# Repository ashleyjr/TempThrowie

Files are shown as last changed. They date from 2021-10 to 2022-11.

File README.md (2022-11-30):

# TempThrowie: Install

## MCUs

   - SDCC : mcs51/z80/z180/r2k/r3ka/gbz80/tlcs90/ds390/TININative/ds400/hc08/s08/stm8 3.5.0
   - SimplicityStudio_v5 flash8051

      - Download from Silicon Labs website
      - Requires 8-bit additonal tools which can be downloaded inside the studio 

   - Silicon Labs 8-Bit USB Debug Adapter

## Basestation (Raspberry Pi)

   - Basestation is a Raspberry Pi Model B Plus Rev 1.2
   - Fresh install of Raspbian GNU/Linux 11 (bullseye)
   - pip install matplotlib
   - sudo apt-get install libatlas-base-dev
   - pip install numpy --upgrade
   - sudo apt install apache2 -y
   - sudo apt-get install php libapache2-mod-php 
   - Config:

```
(21:10 pi@raspberrypi ~) > crontab -l | tail -n 1
*/20 * * * * cd /home/pi/TempThrowie/receiver/software/base/; python throwieAnalysis.py --stats --log stats.log; python throwieAnalysis.py --plotbatttoday --out ../webpage/batttoday.png --log batttoday.log; python throwieAnalysis.py --plottemptoday --out ../webpage/temptoday.png --log temptoday.log; python throwieAnalysis.py --plotbattweek --out ../webpage/battweek.png --log battweek.log; python throwieAnalysis.py --plottempweek --out ../webpage/tempweek.png --log tempweek.log
(21:10 pi@raspberrypi ~) > tail -n 5 /etc/rc.local 
# Run TempThrowie UART monitor
rm /home/pi/TempThrowie/receiver/software/base/throwie.db
cd /home/pi/TempThrowie/receiver/software/base; python throwieLogging.py &

exit 0
(21:10 pi@raspberrypi ~) > cat /etc/apache2/sites-available/000-default.conf | grep DocumentRoot
	DocumentRoot /home/pi/TempThrowie/receiver/software/webpage/
(21:10 pi@raspberrypi ~) > cat /etc/apache2/apache2.conf | grep TempThrowie -A4
<Directory /home/pi/TempThrowie/receiver/software/webpage/>
	Options Indexes FollowSymLinks
	AllowOverride None
	Require all granted
</Directory>
(21:10 pi@raspberrypi ~) > 
```

## Basestation (Laptop)

   - MacBook Pro 2019
   - Virtual Box Virtual Machine
   - Ubuntu 20.04.4 LTS
   - sudo update-alternatives --install /usr/bin/python python /usr/bin/python3 10
   - sudo apt-get install python3-pip
   - python -m pip install pyserial 
   - python -m pip install matplotlib
   - sudo apt install imagemagick-6.q16

# TempThrowie: Spec

## Throwie

### Transmitter

#### Physical

   - Amplitude Modulated (AM) 
   - On Off Keying (OOK) 
   - 433MHz carrier
   - Asynchronous 1K bits per second (pbs) bit stream 

#### Packet

   - A packet is formed of 64 bytes
   - Each byte is sent least signifiant bit first in the following order
     with no spaces

      - Byte0:  The preamble code 0xAA/0x10101010
         ...
      - Byte58: The preamble code 0xAA/0x10101010
      - Byte59: The start code 0x6A/0b01101010
      - Byte60: The throwie identity (ID)
      - Byte61: The temperature reading
      - Byte62: The battery reading
      - Byte63: XOR (Byte3 ^ (Byte2 ^ Byte1))  

#### Collisions

   - Within a collection of throwies the transmit intervals are asynchronous
   
   - A packet is transmitted every 10 minutes
   
   - The 40 bits in each packet takes 40ms to transmit

   - Probability of a collision

      - x = ((n-1) * d) / t

      - n = Number of thowies in collection

      - d = Duration of tranmissions (seconds) = 0.04

      - t = Transmit interval (seconds) = 600

   - Probability of failure when n is

      - 2:     x = 0,04 / 600          = 6.6 * 10^-5
      - 10:    x = (9 * 0,04) / 600    = 6   * 10^-4
      - 256:   x = (255 * 0,04) / 600  = 1.7 * 10^-2
   
   - Mean time between failure at 144 transmissions a day when n is
      
      - 2:     105 days 
      - 10:    12 days    
      - 256:   0.41 days

   - **This does not include failures caused by interference from other devices**

### Measurements

#### Temperature

   - Range between -10C and 50C
   - In the transmitted byte encoding each increment is worth 0.234C ((50 - (-10))/256) 
   - The offset is not calibrated

#### Battery

   - Range between 3.3V and 7V
   - In the transmitted byte encoding each increment is worth 0.014V ((7 - 3.3)/256) 
   - The offset is calibrated and 0 represent the lower voltage

## Receiver

### The serial port 
   
   - Has a baud rate of 115200
   - Transmits 1 start bit 
   - Transmits 8 bit data frame most significant bit first 
   
### Hardware

   - TODO: Spec RF receiver

   - The microcontroller is continually monitoring the output of the receiver 
   - The sample rate is 2KHz 
   - There is a pattern detector searching for the following 8 bytes

      - Byte0: 0b?1?0?1?0
         ...
      - Bytes6: 0b?1?0?1?0
      - Bytes7: 0b?0?1?1?0

   - When the code is detected the next 8 bytes are placed in to a buffer
     and immediately transmitted over the serial port
   - When the last byte is transmitted the microcontroller goes back to 
     pattern detection

### Computer

   - The receiver hardware is connected to a host computer using a serial port   
   - There are two scripts running on the computer

      - The *Logging Script* is continuously running and writing data 
      - The *Analysis Script* may be envoked at anytime and reads the data
       
#### Logging Script

   - The script is called *throwieLogging.py*
   - The serial port is continuously monitored 
   
      - When a frame is received a timeout window opens 
      - The window closes when no frame is recieved for 2 seconds
      - While the window is open all frames received are placed in to a buffer
      - The depth of the buffer is 500 Bytes

         - As the sample rate of the microcontroller is 2KHz it is impossible to 
           overflow this buffer

   - When the timeout window closes 
      
      - A string is created by draining the buffer
      - Each byte is converted to a two character hexadecimal string   
      - More bytes are added to the right hand side of the string 
      - When the buffer is fully drained the left hand side contains the first byte
        recieved and right hand side contained the last byte recieved

   - The string is written to a log file

      - The file is called **throwie_YYYYMMDD_HHSS.log**

         - Y = Year
         - M = Month
         - D = Day
         - H = Hour (24h)
         - M = Minute

      - The file is located in the same directory as the script  

#### Analysis Script

   - The script is called *throwieAnalysis.py*
   - The setup phase

      - Will open every log file in chronological order
      - Create a list of transmissions containing 

         - The date
         - The time
         - The 

      - If the log file contains 8 bytes of data it will analyse

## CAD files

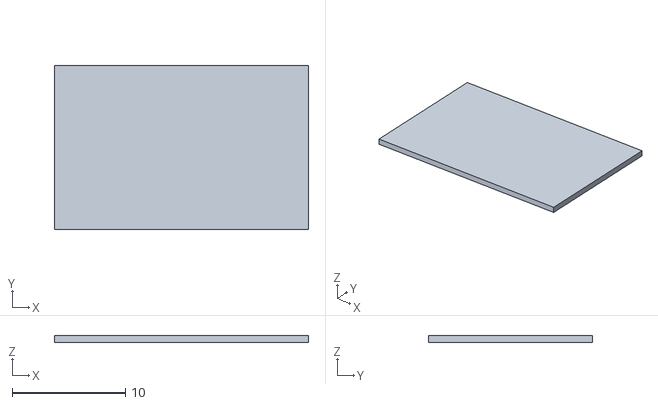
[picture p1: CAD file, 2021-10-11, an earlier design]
throwie/caseworks/RevA/pcb.stl
22.4 x 14.5 x 0.6

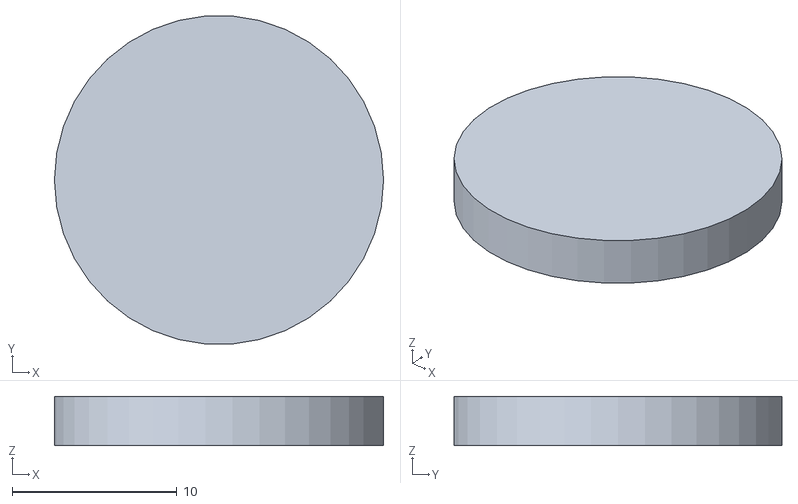
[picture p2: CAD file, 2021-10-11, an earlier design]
throwie/caseworks/RevA/battery.stl
20.0 x 19.9 x 3.00

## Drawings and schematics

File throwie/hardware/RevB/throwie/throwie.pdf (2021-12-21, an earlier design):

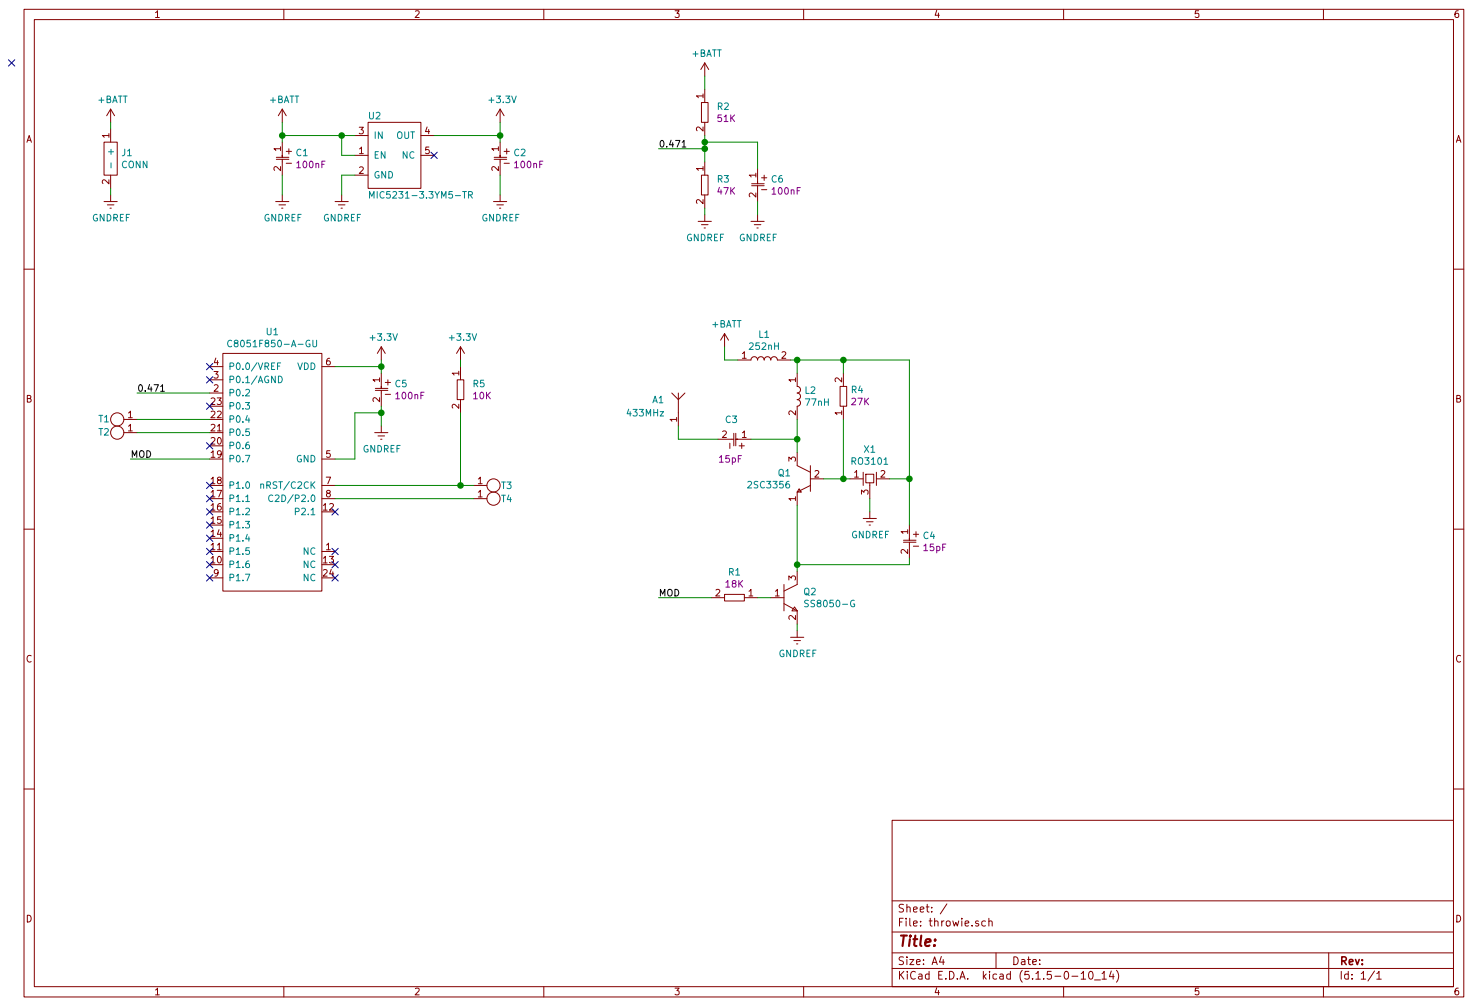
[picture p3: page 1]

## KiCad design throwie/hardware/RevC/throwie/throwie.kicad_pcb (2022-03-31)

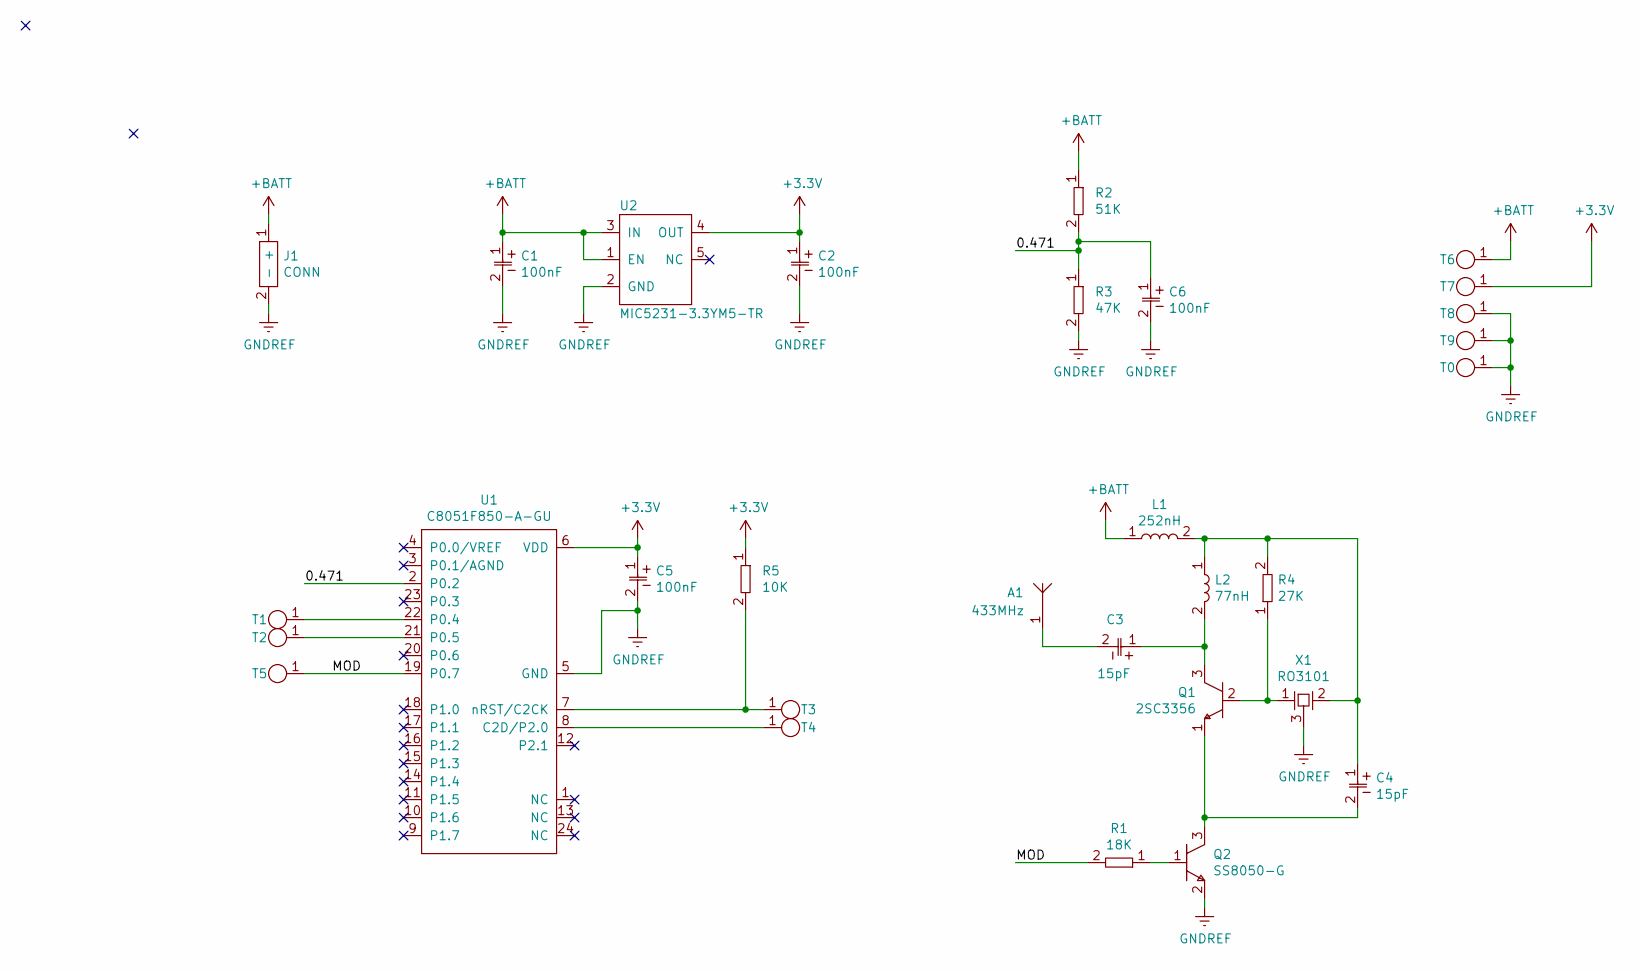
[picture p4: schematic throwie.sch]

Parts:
A1: 433MHz
C1, C2, C3, C4, C5, C6: CAP_0603; 0603
J1: CONN
L1: 252nH
L2: 77nH
Q1: 2SC3356
Q2: SS8050-G
R1, R2, R3, R4, R5: RES_0603; 0603
T0, T1, T2, T3, T4, T5, T6, T7, T8, T9: TestPoints; TestPoint
U1: C8051F850-A-GU
U2: MIC5231-3.3YM5-TR; MIC5231
X1: RO3101; R03101

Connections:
+3V3: C2.1, C5.1, R5.1, T7.1, U1.6 (VDD), U2.4 (OUT)
+BATT: C1.1, J1.1 (+), L1.1, R2.1, T6.1, U2.1 (EN), U2.3 (IN)
/0.471: C6.1, R2.2, R3.1, U1.2 (P0.2)
/MOD: R1.2, T5.1, U1.19 (P0.7)
GNDREF: C1.2, C2.2, C5.2, C6.2, J1.2 (-), Q2.2, R3.2, T0.1, T8.1, T9.1, U1.5 (GND), U2.2 (GND), X1.3
unnamed: A1.1, C3.2
unnamed: C3.1, L2.2, Q1.3
unnamed: C4.1, L1.2, L2.1, R4.2, X1.2
unnamed: C4.2, Q1.1, Q2.3
unnamed: Q1.2, R4.1, X1.1
unnamed: Q2.1, R1.1
unnamed: R5.2, T3.1, U1.7 (nRST/C2CK)
unnamed: T1.1, U1.22 (P0.4)
unnamed: T2.1, U1.21 (P0.5)
unnamed: T4.1, U1.8 (C2D/P2.0)

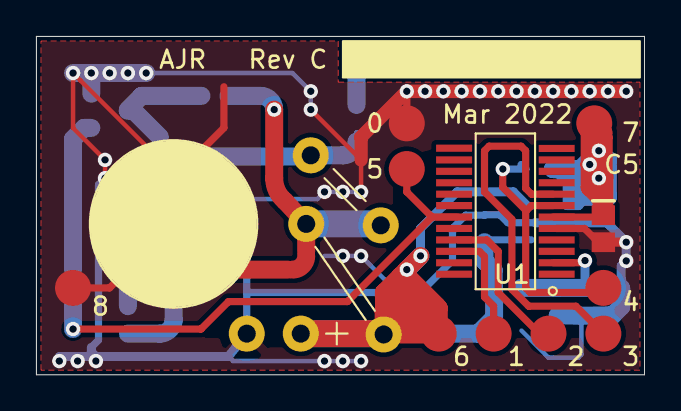
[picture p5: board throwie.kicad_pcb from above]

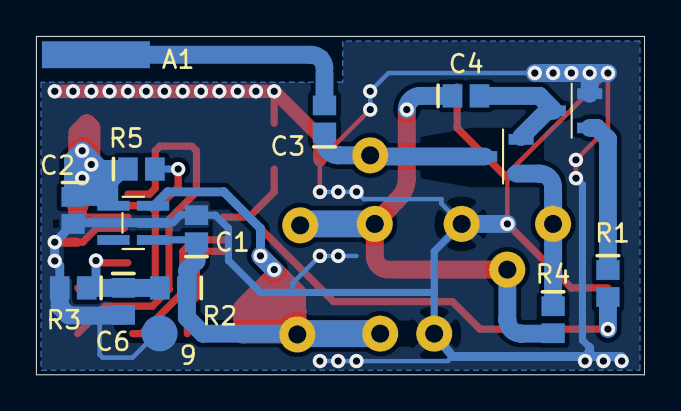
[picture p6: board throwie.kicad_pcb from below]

Board: 2 copper layers, 33.8 x 18.8 mm, 30 parts (15 on the bottom side), 15 nets.

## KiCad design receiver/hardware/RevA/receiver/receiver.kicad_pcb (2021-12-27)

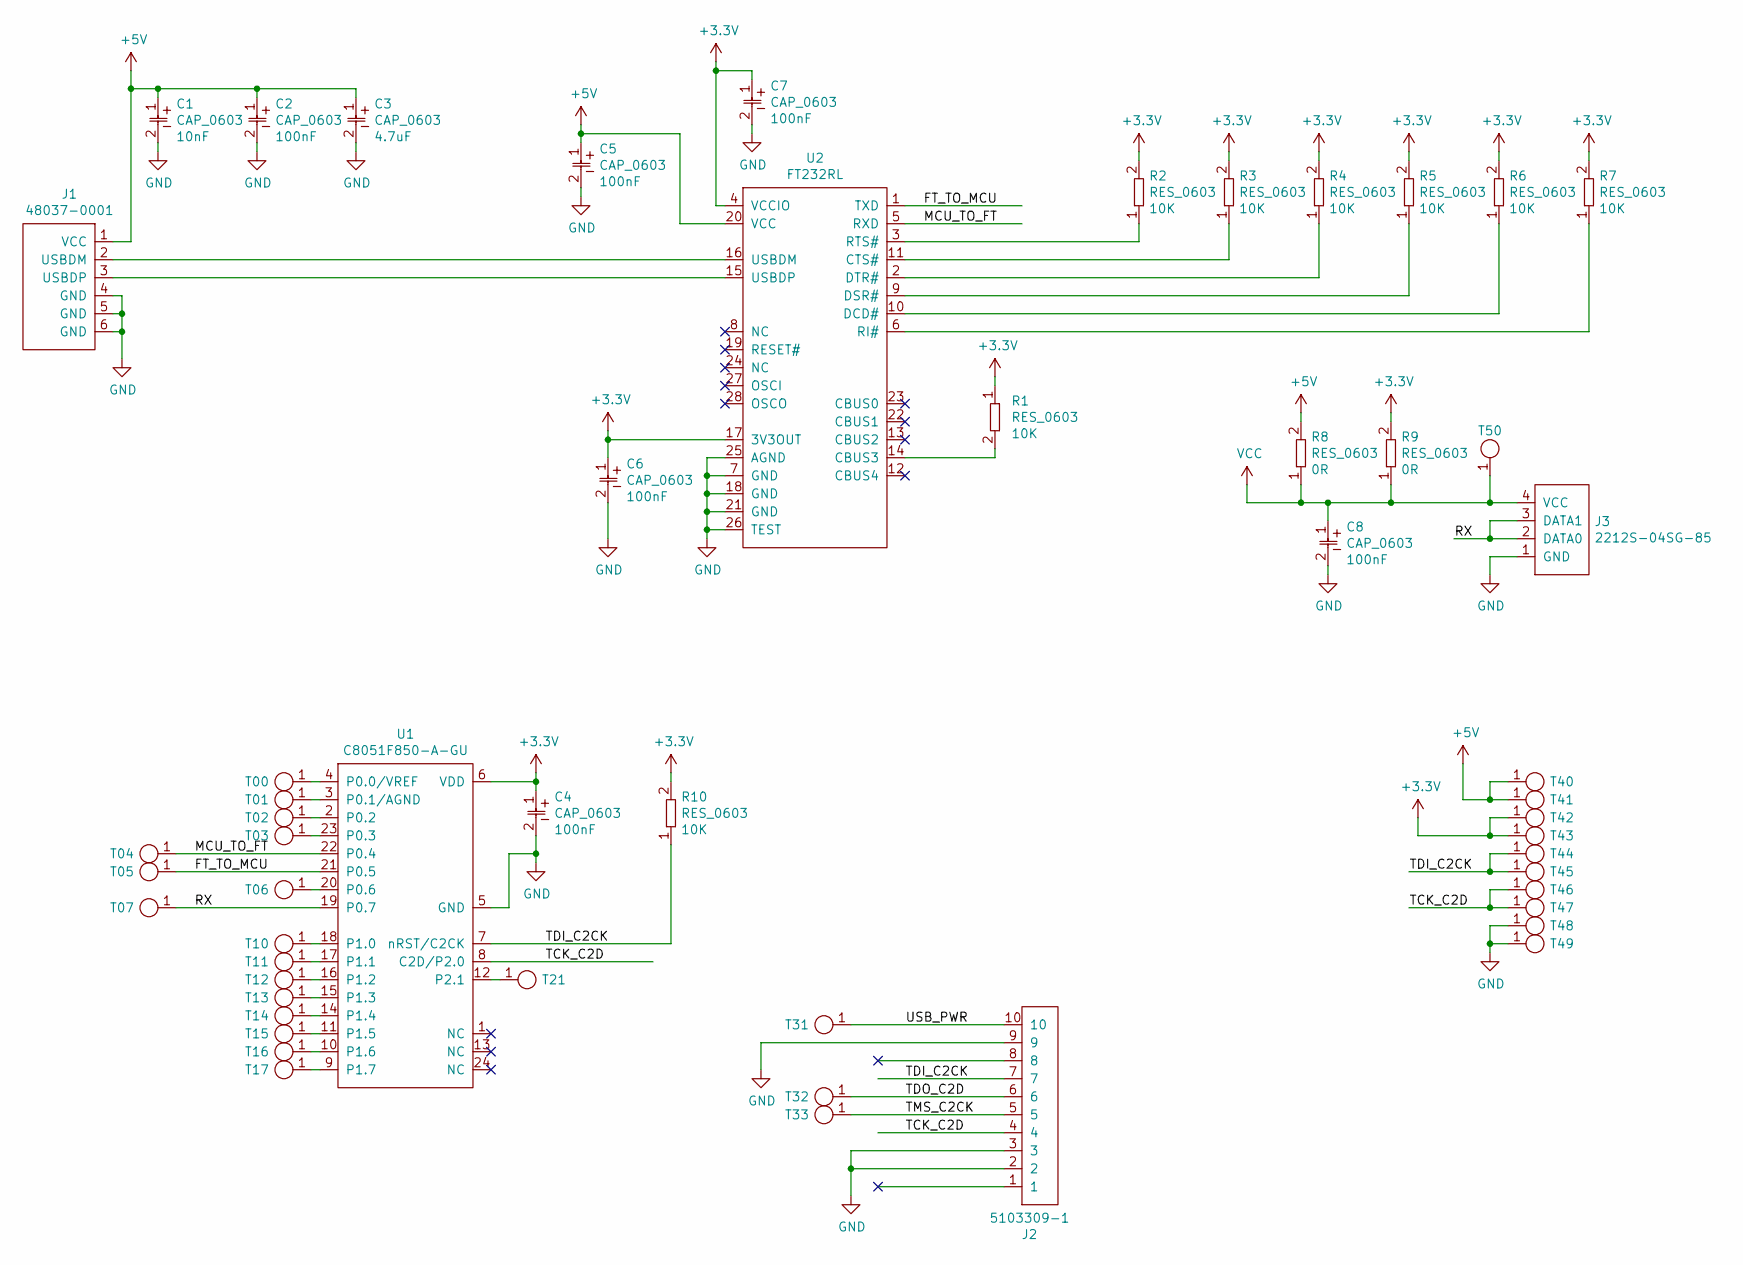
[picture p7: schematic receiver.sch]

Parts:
C1, C2, C3, C4, C5, C6, C7, C8: CAP_0603; 0603
J1: 48037-0001
J2: 5103309-1
J3: 2212S-04SG-85
R1, R2, R3, R4, R5, R6, R7, R8, R9, R10: RES_0603; 0603
T00, T01, T02, T03, T04, T05, T06, T07, T10, T11, T12, T13, T14, T15, T16, T17, T21, T31, T32, T33, T40, T41, T42, T43, T44, T45, T46, T47, T48, T49, T50: TestPoints; TestPoint
U1: C8051F850-A-GU
U2: FT232RL

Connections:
+3V3: C4.1, C6.1, C7.1, R1.1, R2.2, R3.2, R4.2, R5.2, R6.2, R7.2, R9.2, R10.2, T42.1, T43.1, U1.6 (VDD), U2.4 (VCCIO), U2.17 (3V3OUT)
+5V: C1.1, C2.1, C3.1, C5.1, J1.1 (VCC), R8.2, T40.1, T41.1, U2.20 (VCC)
/FT_TO_MCU: T05.1, U1.21 (P0.5), U2.1 (TXD)
/MCU_TO_FT: T04.1, U1.22 (P0.4), U2.5 (RXD)
/RX: J3.2 (DATA0), J3.3 (DATA1), T07.1, U1.19 (P0.7)
/TCK_C2D: J2.4, T46.1, T47.1, U1.8 (C2D/P2.0)
/TDI_C2CK: J2.7, R10.1, T44.1, T45.1, U1.7 (nRST/C2CK)
/TDO_C2D: J2.6, T32.1
/TMS_C2CK: J2.5, T33.1
/USB_PWR: J2.10, T31.1
GND: C1.2, C2.2, C3.2, C4.2, C5.2, C6.2, C7.2, C8.2, J1.4 (GND), J1.5 (GND), J1.6 (GND), J2.2, J2.3, J2.9, J3.1 (GND), T48.1, T49.1, U1.5 (GND), U2.7 (GND), U2.18 (GND), U2.21 (GND), U2.25 (AGND), U2.26 (TEST)
unnamed: J1.2 (USBDM), U2.16 (USBDM)
unnamed: J1.3 (USBDP), U2.15 (USBDP)
unnamed: R1.2, U2.14 (CBUS3)
unnamed: R2.1, U2.3 (RTS#)
unnamed: R3.1, U2.11 (CTS#)
unnamed: R4.1, U2.2 (DTR#)
unnamed: R5.1, U2.9 (DSR#)
unnamed: R6.1, U2.10 (DCD#)
unnamed: R7.1, U2.6 (RI#)
unnamed: T00.1, U1.4 (P0.0/VREF)
unnamed: T01.1, U1.3 (P0.1/AGND)
unnamed: T02.1, U1.2 (P0.2)
unnamed: T03.1, U1.23 (P0.3)
unnamed: T06.1, U1.20 (P0.6)
unnamed: T10.1, U1.18 (P1.0)
unnamed: T11.1, U1.17 (P1.1)
unnamed: T12.1, U1.16 (P1.2)
unnamed: T13.1, U1.15 (P1.3)
unnamed: T14.1, U1.14 (P1.4)
unnamed: T15.1, U1.11 (P1.5)
unnamed: T16.1, U1.10 (P1.6)
unnamed: T17.1, U1.9 (P1.7)
unnamed: T21.1, U1.12 (P2.1)
VCC: C8.1, J3.4 (VCC), R8.1, R9.1, T50.1

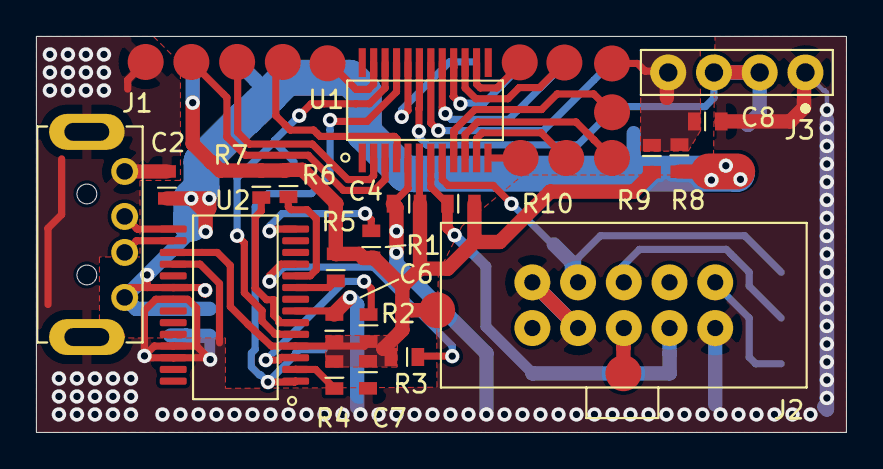
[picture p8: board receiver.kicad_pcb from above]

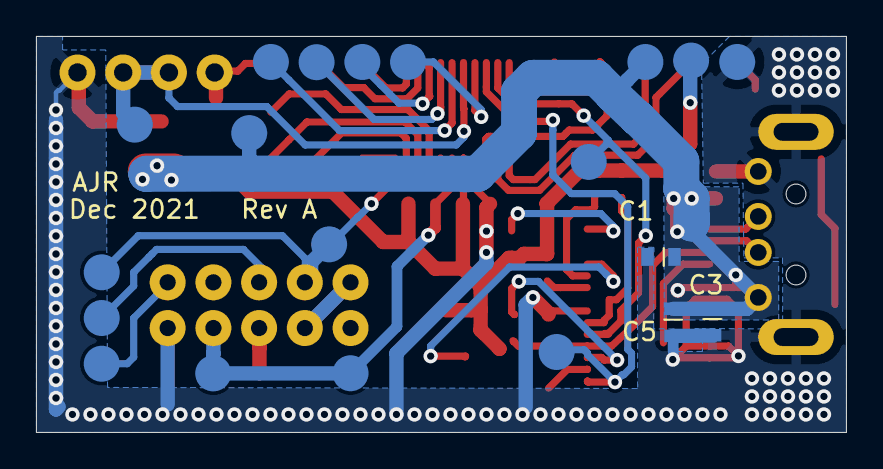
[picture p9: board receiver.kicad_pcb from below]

Board: 2 copper layers, 45.0 x 22.0 mm, 54 parts (20 on the bottom side), 35 nets.

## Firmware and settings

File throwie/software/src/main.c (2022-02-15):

//-----------------------------------------------------------------------------
// Includes
//-----------------------------------------------------------------------------

#include "SI_C8051F850_Register_Enums.h"
#include "SI_C8051F850_Defs.h"

//-----------------------------------------------------------------------------
// Defines
//-----------------------------------------------------------------------------

// #define DBG_LED
#define DBG_UART
// #define ID              0 // Defined in makefile
#define ID_IDX             0
#define TEMP_IDX           1
#define BATT_IDX           2
#define XOR_IDX            3
#define PAY_SIZE_BYTES     4
#define PAY_SIZE_BITS      (8*PAY_SIZE_BYTES)
#define PRE_SIZE_BYTES     4
#define PRE_SIZE_BITS      (8*PRE_SIZE_BYTES)
#define SRT_SIZE_BYTES     1
#define SRT_SIZE_BITS      (8*SRT_SIZE_BYTES)
#define PRE_SRT_SIZE_BITS  (PRE_SIZE_BITS+SRT_SIZE_BITS)
#define PKT_SIZE_BITS      (PRE_SIZE_BITS+SRT_SIZE_BITS+PAY_SIZE_BITS)
#define SRT_CODE           0xAA

////////////////////////////////////////////
// These are the setting for a Rev C device
//
//  64 * 1023 = 65472 = 1.65V
//  (ADC does 64 reads and accumlates)
//
//  757mV @ 0C
//  2.85mV/C
// 
//  -12C = 722.8mV = 65472*(0.7228/1.65) = 28681 
//   51C = 902.4mV = 65472*(0.9024/1.65) = 35807
//
//   Scale = (35807-28681)/256 = 27.835

#define TEMP_LO 28681 
#define TEMP_HI 35807
#define TEMP_SC 28

SBIT(MOD,  SFR_P0, 7);  
#ifdef DBG_LED
SBIT(LED,  SFR_P1, 1);  
#endif // DBG_LED

//-----------------------------------------------------------------------------
// Global Variables
//-----------------------------------------------------------------------------

volatile U8 clk;
volatile U16 ptr;
volatile U8 payload[PAY_SIZE_BYTES];

//-----------------------------------------------------------------------------
// Prototypes
//-----------------------------------------------------------------------------

#ifdef DBG_UART
void uartTx(U8 tx);
void uartHex(U8 tx);
void uartNum(U16 n);
#endif // DBG_UART
void sleep(void);

//-----------------------------------------------------------------------------
// Main Routine
//-----------------------------------------------------------------------------

void main (void){        
   payload[ID_IDX] = ID; 
   for(;;){ 
       
      sleep(); 
       
      #ifdef DBG_LED
      LED = 1; 
      #endif // DBG_LED
   
      // Read Battery ADC 
      ADC0CN0  = ADC0CN0_ADEN__ENABLED | 
                 ADC0CN0_ADBUSY__SET;
      ADC0MX   = ADC0MX_ADC0MX__ADC0P2;    
      REF0CN   = REF0CN_REFSL__VDD_PIN; 
      ADC0CF   = ADC0CF_ADTM__TRACK_DELAYED | 
                 ADC0CF_ADGN__GAIN_1;          
      ADC0CN1  = ADC0CN1_ADCMBE__CM_BUFFER_ENABLED;
      ADC0AC   = ADC0AC_AD12BE__12_BIT_ENABLED|
                 ADC0AC_ADAE__ACC_ENABLED|
                 ADC0AC_ADRPT__ACC_4;
      ADC0PWR  = (0 << ADC0PWR_ADPWR__SHIFT) | 
                 ADC0PWR_ADLPM__LP_BUFFER_DISABLED | 
                 ADC0PWR_ADMXLP__LP_MUX_VREF_DISABLED | 
                 ADC0PWR_ADBIAS__MODE3; 
      ADC0CN0  = ADC0CN0_ADBMEN__BURST_ENABLED|
                 ADC0CN0_ADEN__ENABLED | 
                 ADC0CN0_ADBUSY__SET;
      while(0 == (ADC0CN0 & ADC0CN0_ADINT__SET)); 
      payload[BATT_IDX] = ADC0 >> 4;  
      
      // Read temperature diode
      ADC0MX   = ADC0MX_ADC0MX__TEMP;    
      REF0CN   = REF0CN_REFSL__INTERNAL_VREF |
                 REF0CN_IREFLVL__1P65 |
                 REF0CN_TEMPE__TEMP_ENABLED; 
      ADC0CF   = ADC0CF_ADTM__TRACK_DELAYED | 
                 ADC0CF_ADGN__GAIN_1;          
      ADC0CN1  = ADC0CN1_ADCMBE__CM_BUFFER_ENABLED;
      ADC0AC   = ADC0AC_AD12BE__12_BIT_ENABLED|
                 ADC0AC_ADAE__ACC_ENABLED|
                 ADC0AC_ADRPT__ACC_64;
      ADC0PWR  = (0 << ADC0PWR_ADPWR__SHIFT) | 
                 ADC0PWR_ADLPM__LP_BUFFER_DISABLED | 
                 ADC0PWR_ADMXLP__LP_MUX_VREF_DISABLED | 
                 ADC0PWR_ADBIAS__MODE3; 
      ADC0CN0  = ADC0CN0_ADBMEN__BURST_ENABLED|
                 ADC0CN0_ADEN__ENABLED | 
                 ADC0CN0_ADBUSY__SET;
      while(0 == (ADC0CN0 & ADC0CN0_ADINT__SET));  
   
      // Scale temp to 8 bits 
      if(ADC0 < TEMP_LO){
         payload[TEMP_IDX] = 0;
      }else{
         if(ADC0 > TEMP_HI){
            payload[TEMP_IDX] = 255;
         }else{
            payload[TEMP_IDX] = (ADC0 - TEMP_LO) / TEMP_SC; 
         }
      } 
     
      // XOR
      payload[XOR_IDX]  = payload[ID_IDX];
      payload[XOR_IDX] ^= payload[TEMP_IDX];
      payload[XOR_IDX] ^= payload[BATT_IDX];

      // Zero pointer and start sending 
      ptr = 0;
      IE |= IE_EA__ENABLED; 
       
      #ifdef DBG_UART
      uartHex(payload[ID_IDX]);
      uartHex(payload[TEMP_IDX]);
      uartHex(payload[BATT_IDX]);
      uartHex(payload[XOR_IDX]);
      uartTx(' ');
      uartTx('(');
      uartTx('T');
      uartTx(':');
      uartNum(payload[TEMP_IDX]);
      uartTx(',');
      uartTx('B');
      uartTx(':');
      uartNum(payload[BATT_IDX]);
      uartTx(')');
      uartTx('\n');
      uartTx('\r');
      #endif  
       
      // Wait until sent
      while(ptr < PKT_SIZE_BITS); 
      
      #ifdef DBG_LED
      LED = 0; 
      #endif // DBG_LED
   };
}
 
//-----------------------------------------------------------------------------
// Interrupt Vectors
//-----------------------------------------------------------------------------

INTERRUPT (TIMER0_ISR, TIMER0_IRQn){
   IE = 0;
}

INTERRUPT (TIMER2_ISR, TIMER2_IRQn){           
   U8 bt; 
   U8 by;
   U8 value;
   
   if(ptr < PRE_SIZE_BITS){
      // PREAMBLE STAGE
      value = 1;
   }else{
      if(ptr < PRE_SRT_SIZE_BITS){
         // START STAGE
         bt  = SRT_CODE >> (ptr -  PRE_SIZE_BITS );
         value = bt & 0x01; 
      }else{
         if (ptr < PKT_SIZE_BITS){
            // PAYLOAD STAGE
            bt  = (ptr - PRE_SRT_SIZE_BITS); 
            by  = bt / 8;
            bt  = bt - (by * 8);
            value = 0x01 & (payload[by] >> bt);  
         }else{
            // STALL
            value = 0;
         }
      }
   }
   // Clock
   clk++;
   clk %= 2;

   // Manchester encoding
   if((ptr <= PKT_SIZE_BITS) && (
         ((clk == 1) && (value == 1))||
         ((clk == 0) && (value == 0)))
      ){ 
      MOD = 1;
   }else{
      MOD = 0;
   }
  
   // Update ready for next phase 
   if(clk == 0){
      ptr++;
   }
  
   TMR2CN &= ~TMR2CN_TF2H__SET;
}


//-----------------------------------------------------------------------------
// Debug UART
//-----------------------------------------------------------------------------

#ifdef DBG_UART
void uartTx(U8 tx){
   SCON0_TI = 0;
   SBUF0 = tx;
   while(!SCON0_TI); 
}

void uartHex(U8 tx){
   U8 i,j;
   for(i=4;i<5;i-=4){
      j = (tx >> i) & 0xF;
      if(j > 9){
         uartTx(j + 'A' - 10);
      }else{
         uartTx(j + '0');
      }
   }

}
void uartNum(U16 tx){
   U16 n;
   U8 i;
   U8 c [5];
   n = tx; 
   for(i=0;i<5;i++){
      c[4-i] = (n % 10);
      n = n - c[4-i];
      n = n / 10;
      c[4-i] += '0';
   }
   for(i=0;i<5;i++){
      uartTx(c[i]); 
   }
}
#endif // DBG_UART

//-----------------------------------------------------------------------------
// Setup/sleep
//-----------------------------------------------------------------------------

void sleep(void){

   // Disabled watchdog
   WDTCN    = 0xDE;
   WDTCN    = 0xAD;

   // Enabled LFOSC
   //    - Set to 10KHz
   OSCLCN = OSCLCN_OSCLEN__DISABLED;
   OSCLCN = OSCLCN_OSCLEN__ENABLED |
            OSCLCN_OSCLD__DIVIDE_BY_8;
   

   // Enabled T1 interrupt
   IE   = IE_EA__ENABLED | 
		    IE_ET0__ENABLED;
   

   // Configure T0
   CKCON  = CKCON_T0M__PRESCALE|
            CKCON_SCA__SYSCLK_DIV_48;  
	TMOD   = TMOD_T0M__MODE1;	 
   TL0    = 0xFA;
   TH0    = 0xFF;
   

   // Main clock is the Low Frequency Clock 
    while(1){
      if(OSCLCN & OSCLCN_OSCLRDY__SET){
         break;
      }
   }
   CLKSEL = CLKSEL_CLKSL__LFOSC|
            CLKSEL_CLKDIV__SYSCLK_DIV_128 ;
   
   // Start T0
   TCON   = TCON_TR0__RUN;     


   // Go to sleep
   PCON = PCON_IDLE__IDLE ;
   PCON = PCON;


   // !!! Get woken up by timer
   

   // Clock
	CLKSEL   = CLKSEL_CLKSL__HFOSC |			     
              CLKSEL_CLKDIV__SYSCLK_DIV_1; 
   
   // Enable IOs
   #ifdef DBG_UART
   P0MDOUT  = P0MDOUT_B4__PUSH_PULL|
              P0MDOUT_B7__PUSH_PULL;
   #else
   P0MDOUT  = P0MDOUT_B7__PUSH_PULL;
   #endif // DBG_UART
   
   #ifdef DBG_LED
   P1SKIP   = P1SKIP_B1__SKIPPED; 
   P1MDOUT  = P1MDOUT_B1__PUSH_PULL;
   #endif // DBG_LED
   
   #ifdef DBG_UART
   XBR0     = XBR0_URT0E__ENABLED;
   #endif // DBG_UART
   
   XBR2     = XBR2_WEAKPUD__PULL_UPS_DISABLED | 
              XBR2_XBARE__ENABLED;
   
   // Setup Timers
   CKCON    = CKCON_T1M__SYSCLK;  
	
   // Timer 1 
   //    - UART
   #ifdef DBG_UART
   TMOD     = TMOD_T1M__MODE2;
	TCON     = TCON_TR1__RUN; 
   TH1      = 0x96;           // Magic values from datasheet for 115200
	TL1      = 0x96;
   #endif // DBG_UART

   // Timer 2
	//    - Frequency 2KHz
   TMR2CN   = TMR2CN_TR2__RUN;
   TMR2L    = 0x00;
   TMR2H    = 0xFC;
   TMR2RLL  = 0x00;
   TMR2RLH  = 0xFC;
  
   // Set clock phase
   clk = 0;

   // Interrupts
   IE = IE_ET2__ENABLED;
}

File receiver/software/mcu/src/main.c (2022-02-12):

//-----------------------------------------------------------------------------
// Includes
//-----------------------------------------------------------------------------

#include "SI_C8051F850_Register_Enums.h"
#include "SI_C8051F850_Defs.h"

//-----------------------------------------------------------------------------
// Defines
//-----------------------------------------------------------------------------

#define DBG_SAMPLE
#define SAMPLE_BYTES 16
#define SAMPLE_BITS (8*SAMPLE_BYTES)
#define PERIOD 10
#define LOCK_PERIODS 10
#define LOCK_SAMPLES (PERIOD*LOCK_PERIODS)
#define SAMPLES (PERIOD*SAMPLE_BITS)

SBIT(RX,       SFR_P0,  7);  
SBIT(SAMPLE,   SFR_P1,  4);  

//-----------------------------------------------------------------------------
// Global Variables
//-----------------------------------------------------------------------------

volatile U16 sm;
volatile U16 send;
volatile char sample0;
volatile char sample1;
volatile char sample2;
volatile char sample;
volatile char sample_last;
volatile char locking;
volatile U8 start;
volatile U32 data;
volatile U16 finish;
volatile U8 pay[4];

//-----------------------------------------------------------------------------
// Prototypes
//-----------------------------------------------------------------------------

void uartTx(U8 tx);
void setup(void);

//-----------------------------------------------------------------------------
// Main Routine
//-----------------------------------------------------------------------------

void main (void){        
   U8 i;
   U8 j;
   U8 nibble;
   sm = 0; 
   send = 0;
   setup();  
   for(;;){
      if(send){
         // Send the data if it passes the checking
         if(pay[3] == (pay[0] ^ pay[1] ^ pay[2])){ 
            for(i=0;i<4;i++){
               for(j=4;j<5;j-=4){
                  nibble = (pay[i] >> j) & 0xF;
                  if(nibble < 10){
                     uartTx(nibble + '0');
                  }else{
                     uartTx(nibble - 10 + 'A');
                  }
               }
            }
            uartTx('\n');
            uartTx('\r');
         }
         send=0;
      }
   };
}
 
//-----------------------------------------------------------------------------
// Interrupt Vectors
//-----------------------------------------------------------------------------

INTERRUPT (TIMER2_ISR, TIMER2_IRQn){            
   U8 stride;
   char decode;

   // Disable all interrupts
   IE = 0;   
   SAMPLE=1;
   
   
   stride = sm % PERIOD;

   // Pattern search state machine
   // x000xx111xx000xx111...
   if(sm < LOCK_SAMPLES){ 
      locking = 1;
      start = 0;
      switch(stride){ 
         case 0:
         case 1:  
         case 2:  
         case 3:  
         case 4:  if(RX == 0) sm++;  
                  else        sm=0; 
                  break;  
         case 5:
         case 6:  
         case 7:  
         case 8:  
         case 9:  if(RX == 1) sm++;  
                  else        sm=0; 
                  break; 
         default: sm++;             
                  break;
      }
   
   // Take 3 samples and use the median as the sample
   // xABCxxABCxxABCxxABC...
   }else{
      switch(stride){ 
         case 0:  
         case 5:  sample = RX;
                  break;
         case 1: 
         case 2:
         case 3:
         case 6:
         case 7:
         case 8:  sample += RX;  
                  break; 
         case 9:  sample += RX;
                  
                  if(sample > 2){
                     sample_last = 1;
                  }else{
                     sample_last = 0;
                  }
                  break;
         
         case 4:  sample += RX;
                  
                  if(sample > 2){
                     sample = 1;
                  }else{
                     sample = 0;
                  }
                  
                  if((sample_last == 0) && (sample == 1)){
                     decode = 0;
                  }else{
                     if((sample_last == 1) && (sample == 0)){
                        decode = 1; 
                     }
                  }

                  if(locking){
                     start = start >> 1;
                     start |= decode << 7;
                     if(start == 0xAA){
                        locking = 0;
                        data = 0;
                        finish = 0;
                     }
                  }else{
                     if(finish < 32){
                        pay[finish>>3] = pay[finish>>3] >> 1;
                        pay[finish>>3] |= decode << 7;
                        finish++;
                        if(finish == 32){
                           send = 1;
                        }
                     }
                  }


                  break; 
      } 
      sm++;
      if(sm > (SAMPLES+LOCK_SAMPLES)){  
         sm=0;
      }
      SAMPLE=0;  

   }
   

   // Enable the interrupts
   TMR2CN &= ~TMR2CN_TF2H__SET;
   IE = IE_EA__ENABLED | 
        IE_ET2__ENABLED;  
} 

//-----------------------------------------------------------------------------
// UART
//-----------------------------------------------------------------------------

void uartTx(U8 tx){ 
   SCON0_TI = 0;
   SBUF0 = tx;
   while(!SCON0_TI); 
}

//-----------------------------------------------------------------------------
// Setup
//-----------------------------------------------------------------------------

void setup(void){

   // Disabled watchdog
   WDTCN    = 0xDE;
   WDTCN    = 0xAD;

	CLKSEL   = CLKSEL_CLKSL__HFOSC |			     
              CLKSEL_CLKDIV__SYSCLK_DIV_1; 
   
   // Enable IOs 
   P0SKIP   = P0SKIP_B7__SKIPPED; 


   //P0MDIN   = P0MDIN_B7__DIGITAL; 
   //P0SKIP   = P0SKIP_B7__SKIPPED; 
   //P0MDOUT  = P0MDOUT_B4__PUSH_PULL; 
  
   #ifdef DBG_SAMPLE 
   P1MDOUT  = P1MDOUT_B4__PUSH_PULL; 
   #endif

   XBR0     = XBR0_URT0E__ENABLED; 
   XBR2     = XBR2_WEAKPUD__PULL_UPS_DISABLED | 
              XBR2_XBARE__ENABLED;
   
   // Setup Timers
   CKCON    = CKCON_T1M__SYSCLK| 
              CKCON_T2ML__SYSCLK|
              CKCON_T2MH__SYSCLK;

   // Tiemr 1: UART 
   TMOD     = TMOD_T1M__MODE2;
	TCON     = TCON_TR1__RUN; 
   TH1      = 0x96;           // Magic values from datasheet for 115200
	TL1      = 0x96; 

   // Timer 2: 
   //    - Runs as fast as possible
   //    - 10KHz 
	TMR2CN   = TMR2CN_TR2__RUN; 
   TMR2L    = 0x62;
   TMR2H    = 0xF6;
   TMR2RLL  = 0x62;
   TMR2RLH  = 0xF6;
   
   // Interrupts
   IE = IE_EA__ENABLED | 
        IE_ET2__ENABLED;
}

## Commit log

2021-10-06 fab output
    [throwie-B_Cu.gbr, throwie-B_Mask.gbr, throwie-B_Paste.gbr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]
2021-10-07 start caseworks
    [battery.stl, pcb.stl]
2021-10-11 uart working
2021-10-11 started frame build
2021-11-10 fix adc
2021-11-18 start RevB pcb
    [throwie.sch]
2021-11-22 schematic notes
2021-11-23 more layout
    [throwie.kicad_pcb, throwie.sch]
2021-11-24 final layout
    [throwie.kicad_pcb]
2021-11-24 more silk
    [throwie.kicad_pcb, throwie.sch]
2021-11-24 gen revB fab output
    [throwie-B_Cu.gbr, throwie-B_Mask.gbr, throwie-B_Paste.gbr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]
2021-11-24 drill file
    [throwie-B_Cu.gbr, throwie-B_Mask.gbr, throwie-B_Paste.gbr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]
2021-12-05 started sample
2021-12-14 start receiver pcb
    [receiver.kicad_pcb, receiver.sch]
2021-12-16 Added FT232RL
    [receiver.sch]
2021-12-17 ftdi and usb
    [receiver.kicad_pcb, receiver.sch]
2021-12-20 add connector
    [receiver.kicad_pcb, receiver.sch]
2021-12-24 edge cuts
    [receiver.kicad_pcb, receiver.sch]
2021-12-27 finish layout
    [receiver.kicad_pcb, receiver.sch]
2021-12-27 updated with fab output
    [receiver-B_Cu.gbr, receiver-B_Mask.gbr, receiver-B_Paste.gbr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]
2022-01-16 pushing over UART
2022-01-23 always have sample pin
2022-02-01 filter lof
2022-02-08 uart hex
2022-02-12 fix batt adc
2022-03-20 fix y axis invert
    [throwieAnalysis.py]
2022-03-30 started throwie RevC
    [throwie.kicad_pcb, throwie.sch]
2022-03-30 added more test points
    [throwie.kicad_pcb, throwie.sch]
2022-03-31 increase pads, update fab output
    [throwie-B_Cu.gbr, throwie-B_Mask.gbr, throwie-B_Paste.gbr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]
2022-03-31 increase pads
    [throwie.kicad_pcb]
2022-03-31 adjust floods
    [throwie-B_Cu.gbr, throwie-B_Mask.gbr, throwie-B_Paste.gbr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]
2022-03-31 fix back silk
    [throwie-B_Cu.gbr, throwie-B_Mask.gbr, throwie-B_Paste.gbr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]
2022-05-08 holes in jig top for probes
2022-12-10 rev f case
